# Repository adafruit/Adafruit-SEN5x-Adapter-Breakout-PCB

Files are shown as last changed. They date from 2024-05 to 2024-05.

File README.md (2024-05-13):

## Adafruit SEN54 or SEN55 Adapter Breakout - STEMMA QT / Qwiic PCB

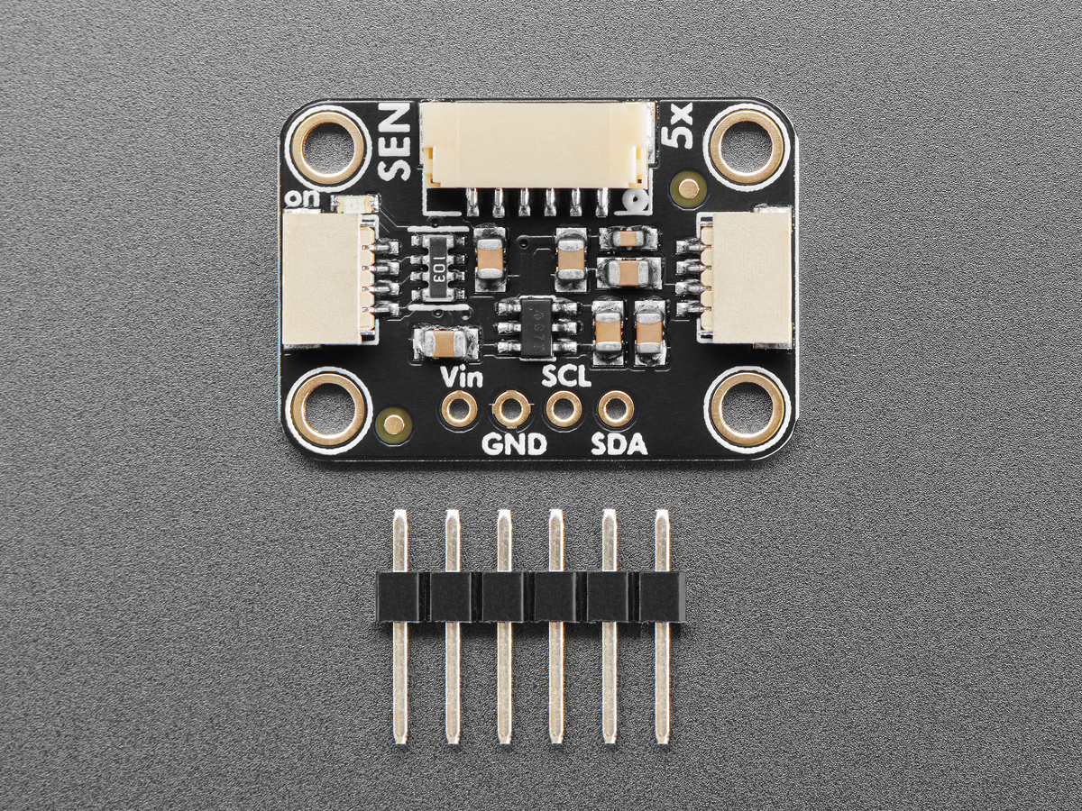
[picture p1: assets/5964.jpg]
<a href="http://www.adafruit.com/products/5964"><br/>
Click here to purchase one from the Adafruit shop</a>

PCB files for the Adafruit SEN54 or SEN55 Adapter Breakout - STEMMA QT / Qwiic. 

Format is EagleCAD schematic and board layout
* https://www.adafruit.com/product/5964

### Description

Now you can quickly integrate the Sensirion SEN54 / SEN55 environmental sensor node into your microcontroller or microcomputer project, with no soldering or fiddly breadboarding - thanks to this here Adafruit SEN54 or SEN55 Adapter Breakout. We covered the awesome Sensirion SEN54 / SEN55 environmental sensor nodes on EYE ON NPI a while ago, it's an awesome all-in-one air quality sensor, but has the annoyance that it requires 5V power and it has a special cable connection.

This adapter breakout will make an instant friendship with all SEN5x boards, thanks to a JST GH-compatible connector in the middle so that you can plug a 6-pin GH cable directly between your SEN and this adapter. In the middle is a small switch-cap boost converter that will generate 5V at 100mA to power the fan and electronics in the SEN5x even if you're using 3V power and logic. Then you can use any ol' STEMMA QT cable to plug into your Metro, Feather, QT Py, Raspberry Pi, etc etc. I2C port.

Once you've got it plugged together, you can run Sensirion's Arduino library or Raspberry Pi Python library to read temperature, humidity, VOC, Particulate Matter PM1 / PM2.5 / PM4 and PM10. (NOx reading is also available on the SEN55)

Please note: this board does NOT come with a JST GH-compatible cable NOR a SEN5x sensor! You can pick up the cable here, and a SEN5x from DigiKey.

### License

Adafruit invests time and resources providing this open source design, please support Adafruit and open-source hardware by purchasing products from [Adafruit](https://www.adafruit.com)!

Designed by Limor Fried/Ladyada for Adafruit Industries.

Creative Commons Attribution/Share-Alike, all text above must be included in any redistribution. 
See license.txt for additional details.

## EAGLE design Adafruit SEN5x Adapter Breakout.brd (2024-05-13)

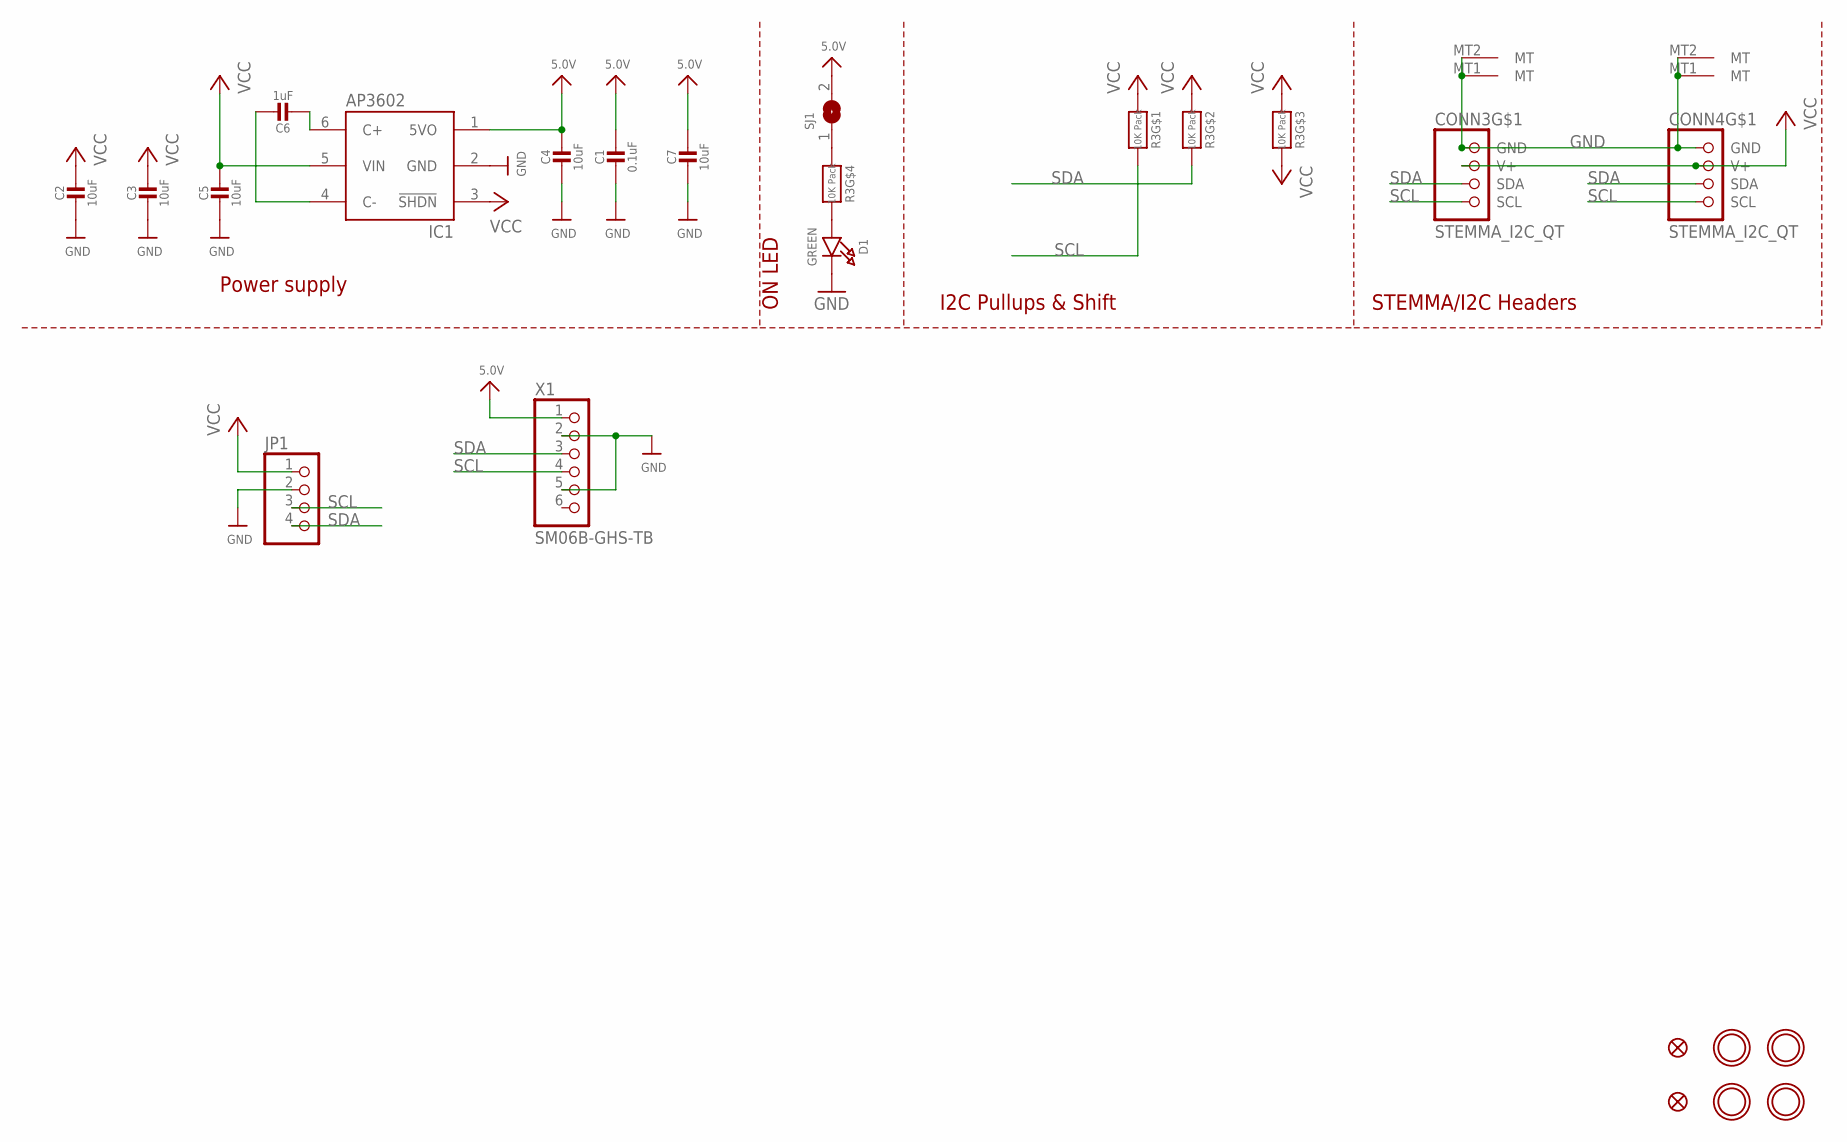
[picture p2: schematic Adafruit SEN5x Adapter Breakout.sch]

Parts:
C1: 0.1uF; 0603-NO
C2, C3, C4, C5, C7: 10uF; 0805-NO
C6: 1uF; 0805-NO
CONN3, CONN4: STEMMA_I2C_QT; JST_SH4
D1: GREEN; CHIPLED_0603_NOOUTLINE
FID3, FID4: FIDUCIAL_1MM
IC1: AP3602/RT9361; SOT23-6
JP1: HEADER-1X4ROUND; 1X04_ROUND
R3: 10K Pack; RESPACK_4X0603
SJ1: SOLDERJUMPERCLOSED; SOLDERJUMPER_CLOSEDWIRE
U$1, U$17, U$19, U$21: MOUNTINGHOLE2.5; MOUNTINGHOLE_2.5_PLATED
X1: SM06B-GHS-TB; CONN_SM06B-GHS-TB_JST

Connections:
5.0V: C1.1, C4.1, C7.1, IC1.1 (5VO), SJ1.2, X1.1
GND: C1.2, C2.2, C3.2, C4.2, C5.2, C7.2, CONN3.1 (GND), CONN3.MT1 (MT), CONN3.MT2 (MT), CONN4.1 (GND), CONN4.MT1 (MT), CONN4.MT2 (MT), D1.C, IC1.2 (GND), JP1.2, X1.2, X1.5
unnamed: D1.A, R3.5 (2)
unnamed: R3.4 (1), SJ1.1
unnamed: C6.2, IC1.6 (C+)
unnamed: C6.1, IC1.4 (C-)
SCL: CONN3.4 (SCL), CONN4.4 (SCL), JP1.3, R3.8 (2), X1.4
SDA: CONN3.3 (SDA), CONN4.3 (SDA), JP1.4, R3.7 (2), X1.3
VCC: C2.1, C3.1, C5.1, CONN3.2 (V+), CONN4.2 (V+), IC1.3 (!SHDN), IC1.5 (VIN), JP1.1, R3.1, R3.2 (1), R3.3 (1), R3.6 (2)

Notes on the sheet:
I2C Pullups & Shift
STEMMA/I2C Headers
ON LED
Power supply

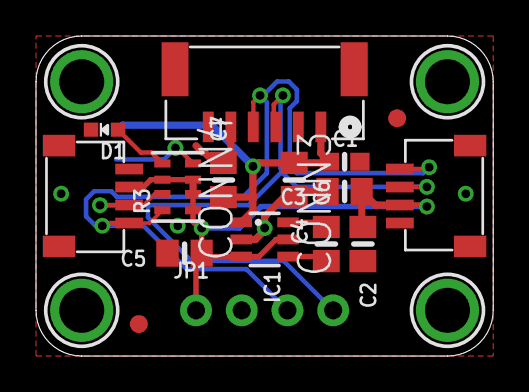
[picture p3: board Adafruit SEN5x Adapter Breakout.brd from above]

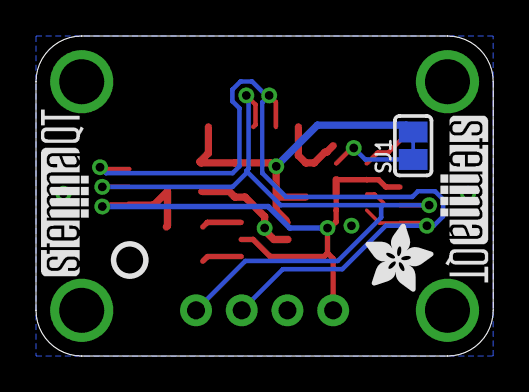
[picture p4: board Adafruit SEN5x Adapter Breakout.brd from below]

Board: 2 copper layers, 25.4 x 17.8 mm, 35 parts (8 on the bottom side), 9 nets.

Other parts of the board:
PLABEL5: PLABEL5
PLABEL13: PLABEL13
PLABEL14: PLABEL14
PLABEL15: PLABEL15
PLABEL16: PLABEL16
PLABEL17: PLABEL17
PLABEL18: PLABEL18
PLABEL19: PLABEL19
PLABEL20: PLABEL20
PLABEL21: PLABEL21
U$15: ADAFRUIT_3.5MM
U$25: PCBFEAT-REV-040
U$30, U$31: STEMMAQT

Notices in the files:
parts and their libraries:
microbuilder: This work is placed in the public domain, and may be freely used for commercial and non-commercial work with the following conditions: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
